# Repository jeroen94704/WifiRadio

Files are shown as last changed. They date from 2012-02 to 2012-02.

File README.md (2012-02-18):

WifiRadio
=========

Introduction
------------

This is the software part of my version of the ubiquitous wifi radio projects. There are many similar builds to be found online, 
and they all use a cheap router as an internet streaming radio, usually running MPD (http://mpd.wikia.com/wiki/Music_Player_Daemon_Wiki) 
to play the music. My build borrows heavily from the radio project by Jeff Keyzer, A.K.A. MightyOhm. He documented the process he 
went through in great detail on his blog, at http://mightyohm.com/blog/2008/10/building-a-wifi-radio-part-1-introduction/

In addition, I also owe a great deal to the SparkFun tutorial "Beginning embedded electronics", which can be found at 
http://www.sparkfun.com/tutorials/57

Contents
--------

The repository contains the following:

* C-code, to be compiled and programmed onto a suitable AVR microcontroller
* A perl script, which runs on the router
* Eagle schematics and board files of the electronics

Features
--------

The firmware+perl script system has the following features:

* Load a predefined playlist containing a set of internet streams
* Browse and play from an MP3 collection located on a network share
* Show currently playing information, including progress in the current track, title/artist info and playlist info

Usage
-----

The player is controlled using a 6-button keypad, with up/down/left/right/enter keys, and a mode switch key. The player starts in radio mode, 
playing the predefined set of internet streams. Pressing the mode switch key will start the MP3 browser mode, and shows the first few MP3 directories 
(in my case, artists). The browser is fully file based, so ID3 tags inside the MP3's are not interpreted. Use up/down to move through the list, press 
"right" to enter a directory, and show what's inside. Press "left" to go up one directory level. Press "enter" to play the currently selected item. If
this is a directory, everything inside that directory and its subdirectories will be played. Pressing the mode switch button again will reload and play
the predefined internet streams once more.

While playing, left/right let you move through the playlist, while up/down controls the volume (not shown on the display).
	
Technical details
-----------------
	
### C-Code

The code was built using the WinAVR suite of tools. You can use the included makefile to build your own binary, which includes targets to set the fuses and program the MPU.

### Perl script

This is a firm departure from Jeff's build, which uses bash scripting to do all the router-side processing. Since I need fairly elaborate two-way communication, involving
a lot of string parsing, using Perl with its built-in regex support was a logical move. The code is a bit dirty in the way it handles 2-way requests (e.g. When the AVR 
asks for a list of tracks). These requests involve receiving a message, processing it, and sending a result back to the AVR. The script forks at startup, so the receiving
and sending parts run in different processes.

When a results needs to be returned to the AVR, the receiver process writes a file containing the response. The sender process detects the existance if this file, reads it, 
sends the data over the serial line, and removes the file. 

More investigation is needed to determine whether the fork is actually necessary. An alternative would be to move to C, and use a proper multithreading approach, but I've 
cracked my skull against setting up an OpenWrt toolchain in the past, and have no immediate desire to attempt this again, also since the current implementation works just fine.

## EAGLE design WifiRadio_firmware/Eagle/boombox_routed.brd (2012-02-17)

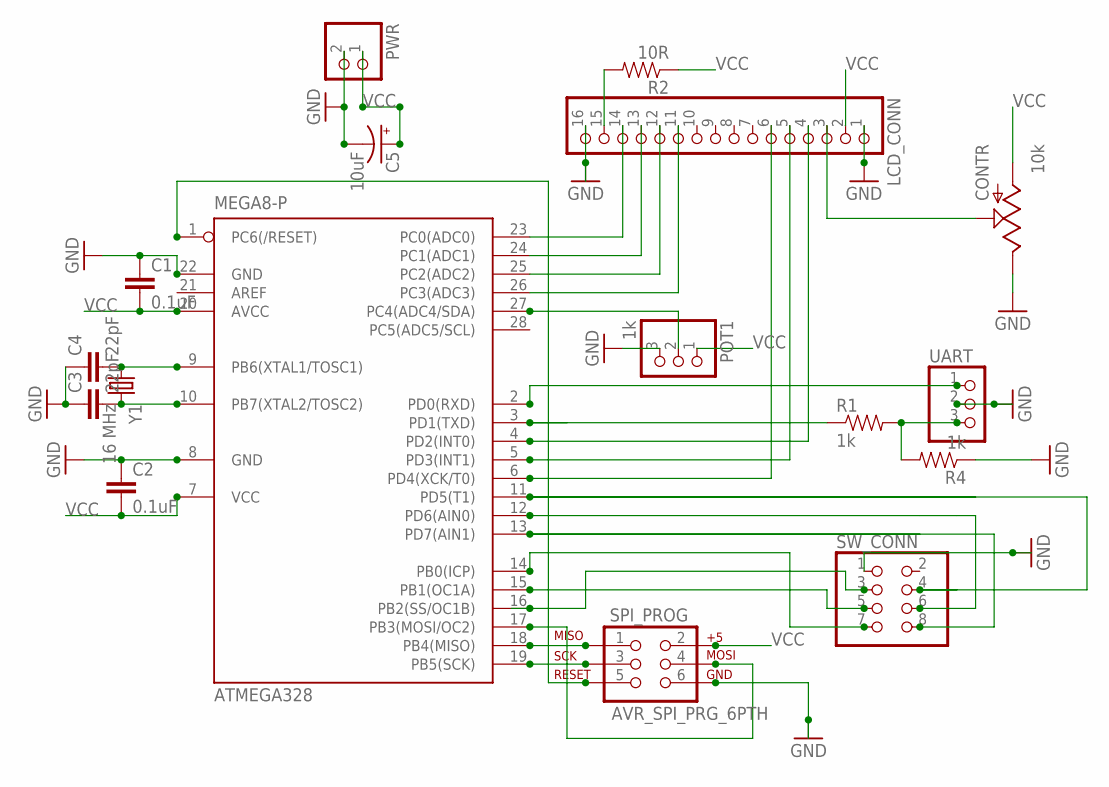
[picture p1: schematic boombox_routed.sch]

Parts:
ATMEGA328: MEGA8-P; DIL28-3
C1, C2: 0.1uF; C2.5-2
C3, C4: 22pF; C2.5-2
C5: 10uF; CPOL-RADIAL-10UF-25V
CONTR: 10k; 3362U
LCD_CONN: PINHD-1X16; 1X16
POT1: 1k; 1X03
PWR: PINHD-1X2; 1X02
R1, R4: 1k; AXIAL-0.4
R2: 10R; AXIAL-0.4
SPI_PROG: AVR_SPI_PRG_6PTH; 2X3
SW_CONN: PINHD-2X4; 2X04
UART: PINHD-1X3; 1X03
Y1: 16 MHz; HC49US

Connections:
GND: ATMEGA328.8 (GND), ATMEGA328.22 (GND), C1.1, C2.1, C3.1, C4.1, C5.2 (-), CONTR.P$1 (E), LCD_CONN.1, LCD_CONN.16, POT1.3, PWR.2, R4.P$1 (1), SPI_PROG.6, SW_CONN.1, UART.2
unnamed: ATMEGA328.10 (PB7(XTAL2/TOSC2)), C3.2, Y1.2
unnamed: ATMEGA328.9 (PB6(XTAL1/TOSC1)), C4.2, Y1.1
unnamed: CONTR.P$2 (S), LCD_CONN.3
unnamed: ATMEGA328.3 (PD1(TXD)), R1.P$1 (1)
unnamed: R1.P$2 (2), R4.P$2 (2), UART.3
unnamed: ATMEGA328.2 (PD0(RXD)), UART.1
unnamed: ATMEGA328.4 (PD2(INT0)), LCD_CONN.4
unnamed: ATMEGA328.5 (PD3(INT1)), LCD_CONN.5
unnamed: ATMEGA328.6 (PD4(XCK/T0)), LCD_CONN.6
unnamed: LCD_CONN.15, R2.P$2 (2)
unnamed: ATMEGA328.23 (PC0(ADC0)), LCD_CONN.14
unnamed: ATMEGA328.24 (PC1(ADC1)), LCD_CONN.13
unnamed: ATMEGA328.25 (PC2(ADC2)), LCD_CONN.12
unnamed: ATMEGA328.26 (PC3(ADC3)), LCD_CONN.11
unnamed: ATMEGA328.19 (PB5(SCK)), SPI_PROG.3
unnamed: ATMEGA328.18 (PB4(MISO)), SPI_PROG.1
unnamed: ATMEGA328.17 (PB3(MOSI/OC2)), SPI_PROG.4
unnamed: ATMEGA328.14 (PB0(ICP)), SW_CONN.7
unnamed: ATMEGA328.27 (PC4(ADC4/SDA)), POT1.2
unnamed: ATMEGA328.15 (PB1(OC1A)), SW_CONN.5
unnamed: ATMEGA328.12 (PD6(AIN0)), SW_CONN.6
unnamed: ATMEGA328.13 (PD7(AIN1)), SW_CONN.8
unnamed: ATMEGA328.11 (PD5(T1)), SW_CONN.4
unnamed: ATMEGA328.16 (PB2(SS/OC1B)), SW_CONN.3
unnamed: ATMEGA328.1 (PC6(/RESET)), SPI_PROG.5
VCC: ATMEGA328.7 (VCC), ATMEGA328.20 (AVCC), C1.2, C2.2, C5.1 (+), CONTR.P$3 (A), LCD_CONN.2, POT1.1, PWR.1, R2.P$1 (1), SPI_PROG.2

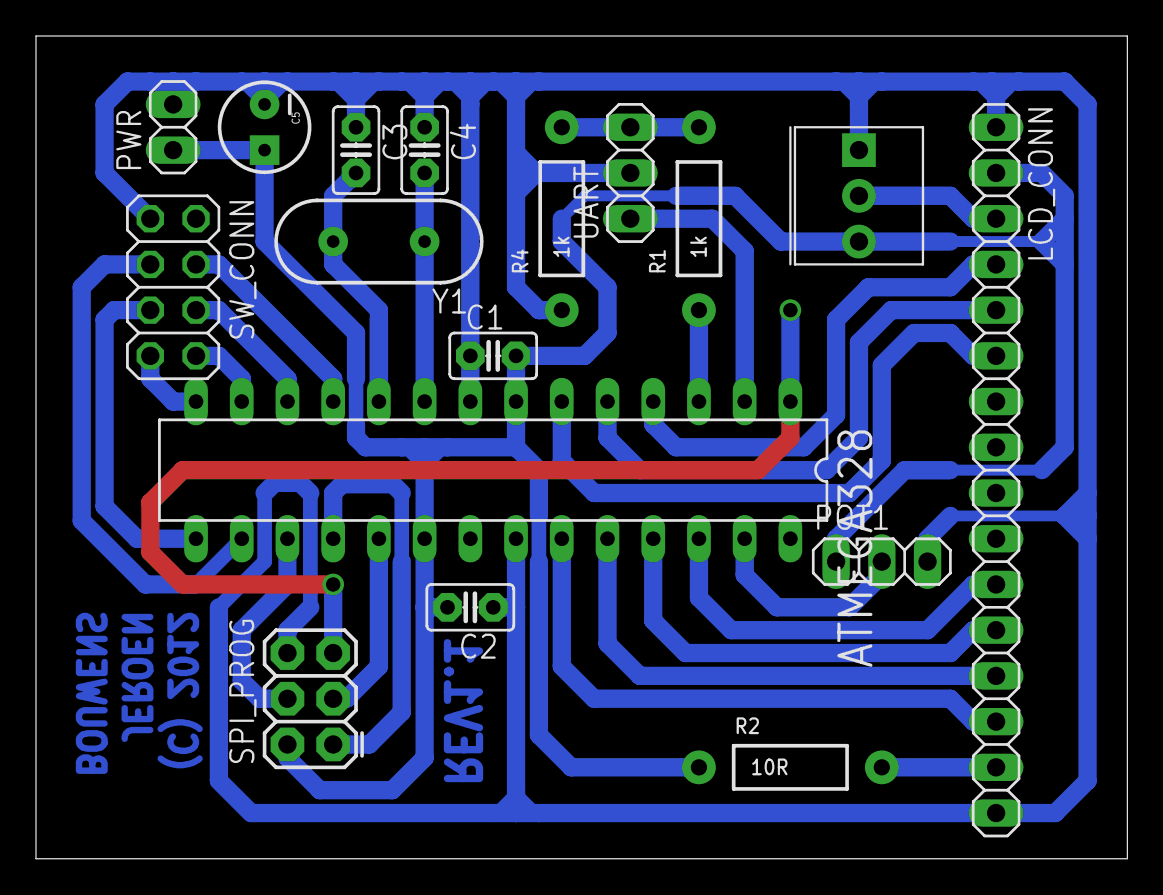
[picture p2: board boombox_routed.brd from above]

Board: 2 copper layers, 60.6 x 45.7 mm, 17 parts (0 on the bottom side), 27 nets.

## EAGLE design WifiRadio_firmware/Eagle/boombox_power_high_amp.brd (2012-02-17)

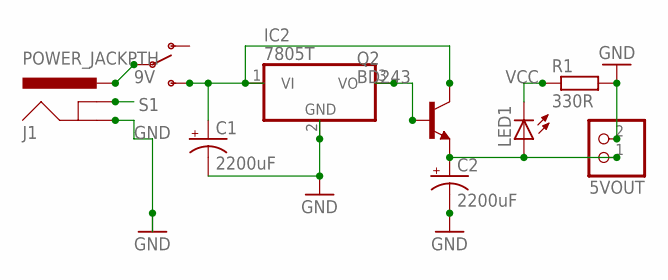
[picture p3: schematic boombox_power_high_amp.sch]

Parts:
5VOUT: PINHD-1X2/90; 1X02/90
C1, C2: 2200uF; CPOL-RADIAL-1000UF-25V
IC2: 7805T; TO220H
J1: POWER_JACKPTH; POWER_JACK_PTH
LED1: LED3MM
Q2: BD243; TO220
R1: 330R; 0309V
S1: SWITCH-SPSTPTH; SWITCH-SPDT

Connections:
9V: C1.1 (+), IC2.1 (VI), Q2.2 (C), S1.3 (S)
GND: 5VOUT.2, C1.2 (-), C2.2 (-), IC2.2 (GND), J1.GND, R1.2
unnamed: 5VOUT.1, C2.1 (+), LED1.A, Q2.3 (E)
unnamed: LED1.K (C), R1.1
unnamed: J1.PWR, S1.2
VCC: IC2.3 (VO), Q2.1 (B)

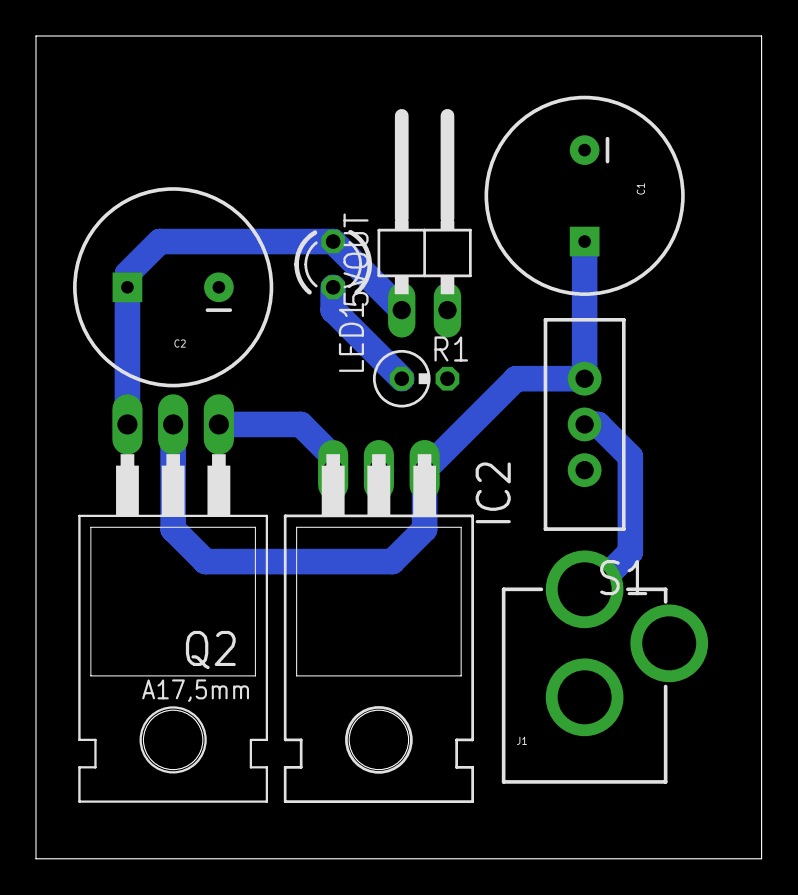
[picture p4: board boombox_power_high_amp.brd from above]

Board: 2 copper layers, 40.3 x 45.7 mm, 9 parts (0 on the bottom side), 6 nets.

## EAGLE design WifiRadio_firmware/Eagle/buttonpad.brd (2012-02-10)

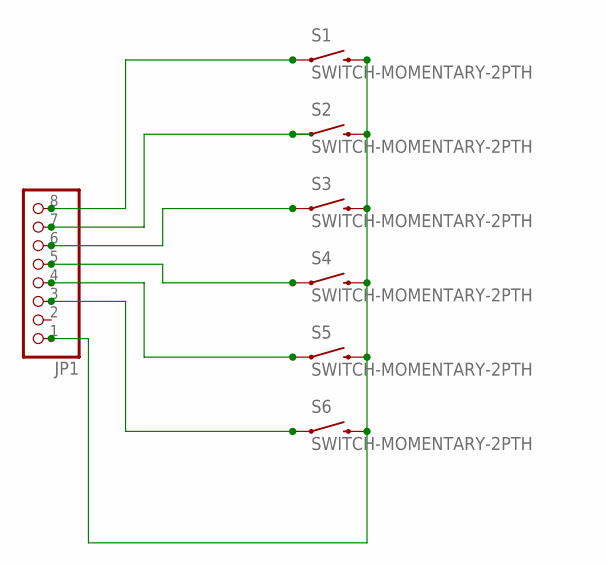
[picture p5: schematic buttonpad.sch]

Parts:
JP1: PINHD-1X8; 1X08
S1, S2, S3, S4, S5, S6: SWITCH-MOMENTARY-2PTH; TACTILE-PTH

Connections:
GND: JP1.1, S1.3 (2), S2.3 (2), S3.3 (2), S4.3 (2), S5.3 (2), S6.3 (2)
unnamed: JP1.8, S1.1
unnamed: JP1.6, S3.1
unnamed: JP1.3, S6.1
unnamed: JP1.7, S2.1
unnamed: JP1.5, S4.1
unnamed: JP1.4, S5.1

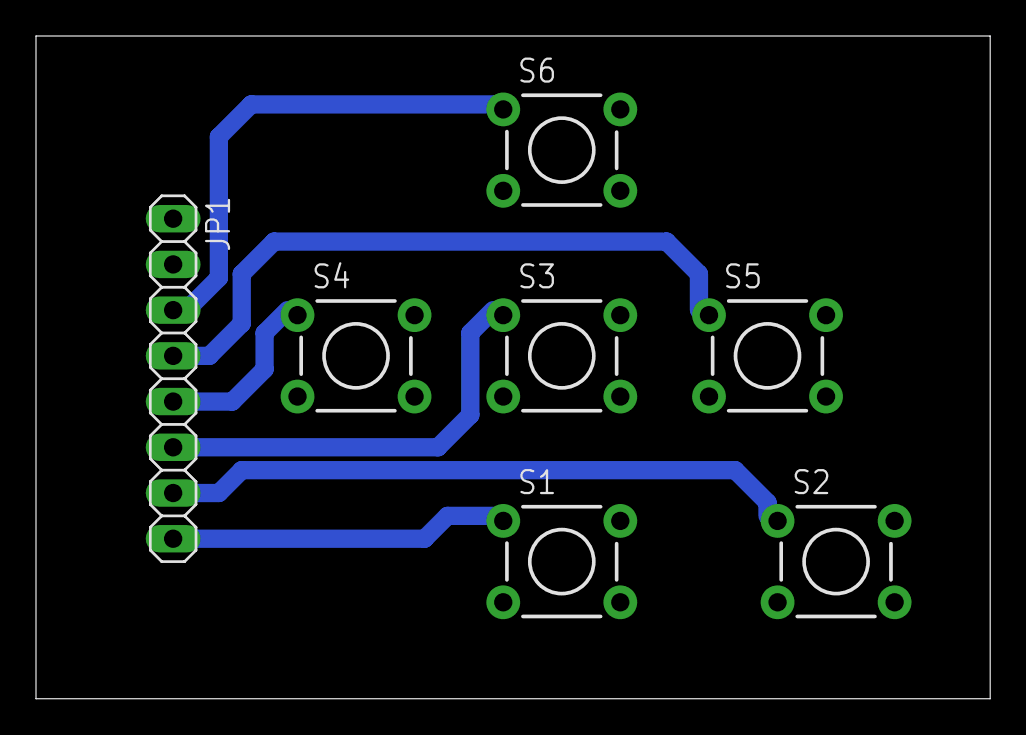
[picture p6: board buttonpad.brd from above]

Board: 2 copper layers, 53.0 x 36.8 mm, 7 parts (0 on the bottom side), 7 nets.

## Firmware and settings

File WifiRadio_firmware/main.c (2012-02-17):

/*
 * Firmware (c)2012 Jeroen Bouwens. Parts of the code were lifted from Jeff Keyzer's 
 * code, and from the SparkFun turorial on beginning embedded electronics. 
 * More information at:
 *
 * http://mightyohm.com/blog/
 *
 * and 
 *
 * http://www.sparkfun.com/tutorials/93
 *
 * Built and tested with an ATmega368 @ 16MHz and a Sparkfun 20x4 character LCD display
 *
 */

//=========== Includes ===========

#include <avr/io.h>
#include <avr/interrupt.h>
#include <util/delay.h>
#include <string.h>
#include <stdio.h>

#include "lcd.h"				// Peter Fleury's LCD Library

//=========== Defines ===========

#define	SER_BUFF_LEN	200		// longest character line to accept from serial port
#define STR_LEN			21		// Longest substring (artist, trackname) to accept. Width of the display + terminating 0
#define	BAUD			9600	// USART baud rate, must agree with router ttyS0 settings
#define	LCD_WIDTH		20		// visible width of LCD display
#define	PAGEDELAY		3000	// delay between LCD pages, in ms

#define BOOL unsigned char
#define TRUE 1
#define FALSE 0

#define UPBUTTON 0
#define DOWNBUTTON 1
#define LEFTBUTTON 2
#define RIGHTBUTTON 3
#define ENTERBUTTON 4
#define SWITCHBUTTON 5

#define UPBUTTONPIN PINB&4
#define DOWNBUTTONPIN PIND&128
#define LEFTBUTTONPIN PINB&2
#define RIGHTBUTTONPIN PIND&32
#define ENTERBUTTONPIN PIND&64
#define SWITCHBUTTONPIN PINB&1

#define PM_PLAYING 0
#define PM_BROWSING 2

//=========== Function prototypes ===========

int atoi ( const char * str );

void inituart(void);
void ioinit(void);
void uart_putchar(unsigned char data);
unsigned char uart_getchar(void);
void uart_flush(void);
void getline(char *serbuffer);
void putstring(char *buffer);
void init_timer1(void);

void lcd_print(char *s);
void processPlayingLine(char *RXserbuffer, char *artist, char *title, int *playlistLength, int *songNum, int *songTime, int *songElapsed);
void displayTime(int songElapsed, int playlistLength, int songNum);
void displayProgressBar(int songLength, int songElapsed);
void displayTrackInfo(char *trackName, char *artistName);
void displayDirEntries(void);
BOOL processButtonPress(int buttonIndex, int buttonPin);
BOOL processResponse(char *RXserbuffer);
void sendCommand(char* command);
void sendCommandParams(char* cmd, int param1, int param2);

char serRXbuffer[SER_BUFF_LEN];	// serial buffer
char serTXbuffer[20];	// serial buffer


//=========== Global Variables ===========

unsigned char gButtonPressSeen;	// Bits used to keep track of which button presses have been seen
unsigned char gPlayerMode;		// Keep track whether we are playing something or browsing the collection
int gCurrentListSelectedIndex;	// The selected item in the sublist of 4 currently shown on the display
int gCurrentListStartIndex;		// The index in the total list of the first item in the current sublist of 4
char gDirEntries[4][STR_LEN];	// Buffer holding track/dir names to display in browsing mode
int gNumDirEntries;				// How many dir entries did I receive? (should always be 1,2,3 or 4)
BOOL gWaitingForReply;			// Indicates whether a request was sent to which a reply is expected but not yet received
int gTimeOutCounter;			// Counter for the response timeout mechanism (in case the router fails to respond)

// Timer1 overflow interrupt service routine (ISR)
SIGNAL (TIMER1_OVF_vect) // SIGNAL call makes sure we don't interrupt the interrupt
{
	TCNT1 = 0x10000 - (F_CPU/1024/10);	// Reset the timer
	
	// Timeout mechanism, just in case the router fails to respond to a button press for 
	// which I expect a reply
	if(gWaitingForReply && gTimeOutCounter < 20)
	{
		gTimeOutCounter++;
	}
	else
	{
		// Timeout occurred
		gWaitingForReply = FALSE;
		gTimeOutCounter=0;
	}
	
	// Don't process button presses while I am are waiting for a reply
	if(!gWaitingForReply)
	{
		// When I am playing, handle button presses accordingly
		if(gPlayerMode == PM_PLAYING)
		{
			if(processButtonPress(UPBUTTON, UPBUTTONPIN) == TRUE)
			{
				sendCommand("cmd:volup\n");  
			}
			if(processButtonPress(DOWNBUTTON, DOWNBUTTONPIN) == TRUE)
			{
				sendCommand("cmd:voldown\n");
			}
			if(processButtonPress(LEFTBUTTON, LEFTBUTTONPIN) == TRUE)
			{
				sendCommand("cmd:prev\n");
			}
			if(processButtonPress(RIGHTBUTTON, RIGHTBUTTONPIN) == TRUE)
			{
				sendCommand("cmd:next\n");
			}
			if(processButtonPress(SWITCHBUTTON, SWITCHBUTTONPIN) == TRUE)
			{
				gPlayerMode = PM_BROWSING;

				// Retrieve the first list of items to show
				gCurrentListStartIndex = 0;
				gCurrentListSelectedIndex = 0;
				sendCommand("cmd:getfirsttracks\n");  
				gWaitingForReply = TRUE;
			}
		}
		// When I am browsing, handle button presses accordingly
		else if(gPlayerMode == PM_BROWSING)
		{
			if(processButtonPress(UPBUTTON, UPBUTTONPIN) == TRUE)
			{
				// Move up in the current sublist of 4 until I hit the top.
				gCurrentListSelectedIndex--;
				if(gCurrentListSelectedIndex == -1 && gCurrentListStartIndex > 0)
				{
					// Move up 4 places in the total list, if this is still possible
					gCurrentListStartIndex -= 4;
					if(gCurrentListStartIndex < 0)
					{
						gCurrentListStartIndex = 0;
					}
					
					// Switching to the "previous" page, so set the bottom entry as selected
					gCurrentListSelectedIndex = 3;
					
					// Retrieve the new list of items to show
					sendCommandParams("gettracks", gCurrentListStartIndex, gCurrentListSelectedIndex);		
					gWaitingForReply = TRUE;
				}
				else
				{
					displayDirEntries();
				}
			}
				
			if(processButtonPress(DOWNBUTTON, DOWNBUTTONPIN) == TRUE)
			{
				// Move down in the current sublist of 4 until I hit the bottom.
				gCurrentListSelectedIndex++;
				
				if(gCurrentListSelectedIndex == 4)
				{
					// Move down 4 places in the total list
					gCurrentListStartIndex += 4;
					
					// Switching to the "next" page, so set the top entry as selected
					gCurrentListSelectedIndex = 0;
					
					// Retrieve the new list of items to show
					sendCommandParams("gettracks", gCurrentListStartIndex, gCurrentListSelectedIndex);		
					gWaitingForReply = TRUE;
				}	
				else
				{
					// In case of a sublist shorter than 4 items, make sure I don't go past the last item
					if(gCurrentListSelectedIndex >= gNumDirEntries)
					{
						gCurrentListSelectedIndex = gNumDirEntries - 1;
					}

					displayDirEntries();
				}
			}
			
			if(processButtonPress(LEFTBUTTON, LEFTBUTTONPIN) == TRUE)
			{
				sendCommand("cmd:dirup\n");
				gCurrentListStartIndex = 0;
				gCurrentListSelectedIndex = 0;
				gWaitingForReply = TRUE;
			}
			
			if(processButtonPress(RIGHTBUTTON, RIGHTBUTTONPIN) == TRUE)
			{
				sendCommandParams("dirdown", gCurrentListStartIndex, gCurrentListSelectedIndex);		
				gCurrentListStartIndex = 0;
				gCurrentListSelectedIndex = 0;
				gWaitingForReply = TRUE;
			}
			
			if(processButtonPress(ENTERBUTTON, ENTERBUTTONPIN) == TRUE)
			{
				gPlayerMode = PM_PLAYING;
				sendCommandParams("play", gCurrentListStartIndex, gCurrentListSelectedIndex);		
			}

			if(processButtonPress(SWITCHBUTTON, SWITCHBUTTONPIN) == TRUE)
			{
				gPlayerMode = PM_PLAYING;
				sendCommand("cmd:loadstreams\n");
			}
		}
	}
}

// Send a command with 2 parameters through the serial port 
void sendCommandParams(char* cmd, int param1, int param2)
{
	char stringBuffer[40];
	sprintf(stringBuffer, "cmd:%s %d %d\n", cmd, param1, param2);
	sendCommand(stringBuffer);		
}

// Handle a button press. This returns TRUE when a new button press on the selected pin is detected 
// Once a button press is detected, the function returns FALSE, until the button is released and 
// pressed again
BOOL processButtonPress(int buttonIndex, int buttonPin)
{
	BOOL result = FALSE;
	
	if(!(gButtonPressSeen & (1 << buttonIndex)))
	{
		if(!(buttonPin))
		{
			gButtonPressSeen |=  (1 << buttonIndex);
			result=TRUE;
		}
	}
	else
	{
		if((buttonPin))
		{
			gButtonPressSeen &=  !(1 << buttonIndex);
		}
		
	}
	
	return result;
}

// Send a string to the router through the serial port
void sendCommand(char* command)
{
	sprintf(serTXbuffer, command);	// Place command in send buffer
	putstring(serTXbuffer);	// transmit over serial link		
}

// Main function. Apart from some initialization, this function contains
// and endless loop which handles messages received from the router over 
// the serial line
int main(void)
{
	char artist[STR_LEN];	// Artist name
	char title[STR_LEN];	// Title of current song
	int playlistLength;		// Length of the playlist
	int songNum;			// song number in the current playlist
	int songTime;			// Total length of the song in seconds
	int songElapsed;		// Elapsed time within the song in seconds
	
    ioinit();		// Setup IO pins and defaults
    inituart();		// initialize AVR serial port (USART0)

	// Blink once to indicate succesful startup
	PORTC = 0b0100000;
	_delay_ms(100);
	PORTC = 0x00;   // All LED's are off

    // initialize LCD display
    lcd_init(LCD_DISP_ON);

    // Display splash screen
    lcd_clrscr();	
    lcd_puts("    MPD Boombox\n   Jeroen Bouwens\n Sponsored by Sioux\n  Embedded Systems");
    _delay_ms(2000);
	
	// Initialize variables and the timer
	gButtonPressSeen = 0;
	gPlayerMode = PM_PLAYING;
	init_timer1();
	sei();		// enable interrupts
    
    // Main program loop
    for(;;) // Loop forever
	{	
		// Grab a line of data from the serial port
		// Note: program execution will stall until serial data is received!
		getline(serRXbuffer);		

		// Blink once when a message was received
		PORTC |= 0b0100000;
		_delay_ms(100);
		PORTC &= 0b1011111;
			
		// If I am playing, show track info
		if(gPlayerMode == PM_PLAYING)
		{
			processPlayingLine(serRXbuffer, artist, title, &playlistLength, &songNum, &songTime, &songElapsed);
				
			lcd_clrscr();	// clear screen

			displayTime(songElapsed, playlistLength, songNum);
			displayProgressBar(songTime, songElapsed);
			displayTrackInfo(title, artist);
		}
		// If I am browsing 
		else
		{
			if(processResponse(serRXbuffer) == TRUE)
			{
				displayDirEntries();
			}
		}
    }
	 
    return 0;   // Never reached
}

void inituart(void)	// Initialize USART0 to desired baud rate
{
	// Set baud rate generator based on F_CPU
	UBRR0H = (unsigned char)(F_CPU/(16UL*BAUD)-1)>>8;
	UBRR0L = (unsigned char)(F_CPU/(16UL*BAUD)-1);
	
	// Enable USART0 transmitter and receiver
	UCSR0B = (1<<RXEN0) | (1<<TXEN0);

}

unsigned char uart_getchar(void)
{
	while(!(UCSR0A & (1 << RXC0)))	// wait until character is received
		;	// do nothing
	
	return UDR0;
}

void uart_putchar(unsigned char data)	// send a character over the serial port
{

	while(!(UCSR0A & (1 << UDRE0))) // wait until UART is ready for tx
		;       // do nothing
	UDR0 = data;    // send char

}

void uart_flush(void)	// flush RX buffer
{
	unsigned char dummy;
	
	while(UCSR0A & (1<<RXC0))	// while there is a character in the RX queue
		dummy = UDR0;			// flush the queue by reading it
}

void getline(char *buffer)	// get a single line from the UART rcvr
{
	int bufpos = 0;
	
	uart_flush();	// clear RX buffer of stale chars if present
	
	// read a line from UART, stop if buffer is full or we reach newline
	while ((bufpos < (SER_BUFF_LEN - 1)) && (buffer[bufpos] = uart_getchar()) != '\n') {

		if (buffer[bufpos] == '\r')
			bufpos--;	// strip carriage returns in case data contains both CR&LF
			
		bufpos++;
	}
	
	buffer[bufpos] = '\0';	// turn buffer into a string
}

void ioinit (void)
{
    //1 = output, 0 = input
    DDRC  |= 0b0100000; // PC5 is output
	
	DDRB  &= 0b11111000; // PB0, 1, 2 are input
	PORTB |= 0b00000111; // Enable internal pull-up resistors	

	DDRD  &= 0b00011111; // PB5, 6, 7 are input
	PORTD |= 0b11100000; // Enable internal pull-up resistors
}

void putstring(char *buffer)	// send a string to the UART
{
	int bufpos = 0;
	
	cli();	// disable interrupts so we don't mangle the data
	
	// start sending characters over the serial port until we reach the end of the string
	while ((bufpos < (SER_BUFF_LEN - 1)) && (buffer[bufpos] != '\0')) 
	{
		uart_putchar(buffer[bufpos]);
			
		bufpos++;
	}
	
	sei();	// enable interrupts again
	
}

void init_timer1(void) 
{
	// initialize TIMER1 to trigger an overflow interrupt every 0.5sec
	TCCR1A = 0;
	TCCR1B |= (1 << CS12) | (1 << CS10);

	
	TCNT1 = 0x10000 - (F_CPU/1024/4);
	
	TIFR1=0;
	TIMSK1 |= (1 << TOIE1);
}

// Process a message in the response format
BOOL processResponse(char *RXserbuffer)
{
	// The following code assumes the message has the following format:
	//		resp: param1,param2,param3,param4
	// It wil store the params in the gDirEntries array. Less than 4 params
	// will also work
	// NOTE: All params, including the last one, must be followed by a comma

	// Check if this is a response message
	char *responsePtr = strstr(RXserbuffer, "resp: ");
	if(responsePtr)
	{
		gNumDirEntries = 0;
		char *respStart = responsePtr + sizeof("resp: ") - 1; // Skip the indentifier part
		char *commaPtr = strstr(respStart, ","); 			   // Find the comma separating param1 and param2
		
		// Assume there are 4 parameters. If less than 4 are found, fill in blanks
		for(int i=0; i<4; i++)
		{
			if(commaPtr)
			{
				int strLen = commaPtr - respStart; 
				strncpy(gDirEntries[i], respStart , strLen);
				gDirEntries[i][strLen] = '\0';		// Make the string zero-terminated
				respStart = commaPtr+1;
				commaPtr = strstr(respStart, ",");
				gNumDirEntries++; 					// Some administration
			}
			else
			{
				gDirEntries[i][0] = '\0';	
			}
		}		
		gWaitingForReply = FALSE;
		return TRUE;
	}
	
	return FALSE;
}

// Process a message in the track information format
void processPlayingLine(char *RXserbuffer, char *artist, char *title, 
						int *playlistLength, int *songNum, int *songTime, int *songElapsed)
{
	// The following code assumes the message has one of the following two formats:
	//
	// 	Artis: <artist> Title: <title> playlistlength: <playlistlength> song: <song> time: <time>
	//
	//  Title: <title> Name: <name> playlistlength: <playlistlength> song: <song> time: <time>
	//
	// Time is in the format <elapsedSeconds>:<totalDurationSeconds>
	// The order of the fields DOES MATTER! 

	char *artistPtr 	= strstr(RXserbuffer, "Artist: ");
	char *titlePtr 		= strstr(RXserbuffer, "Title: ");
	char *namePtr		= strstr(RXserbuffer, "Name: ");
	char *plLengthPtr	= strstr(RXserbuffer, "playlistlength: ");
	char *songPtr 		= strstr(RXserbuffer, "song: ");
	char *timePtr 		= strstr(RXserbuffer, "time: ");

	int stringLength = 0;	

	if(artistPtr && titlePtr)
	{
		char *artistStart = artistPtr + sizeof("Artist: ") - 1;
		stringLength = titlePtr - (artistPtr + sizeof("Artist: ") - 1);
		stringLength = stringLength > 20 ? 20 : stringLength;
		strncpy(artist, artistStart , stringLength);
	}
	artist[stringLength] = '\0';
	
	stringLength = 0;
	if(titlePtr && namePtr) // If we're playing a stream the "artist" field will not be present and there will be a "name" field between title and playlistlength
	{
		char *titleStart = titlePtr + sizeof("Title: ") - 1;			// Skip the field name
		stringLength = namePtr - (titlePtr + sizeof("Title: ") - 1);	// Determine the length of the field value
		stringLength = stringLength > 20 ? 20 : stringLength; 			// Truncate to the maximum width of the display
		strncpy(title, titleStart, stringLength);						// Copy the field value to the appropriate buffer
	}
	else if(titlePtr && plLengthPtr) // There's no "name" field, so we're playing an MP3 and there will be a playlistlength field after the title
	{
		char *titleStart = titlePtr + sizeof("Title: ") - 1;
		stringLength = plLengthPtr - (titlePtr + sizeof("Title: ") - 1);
		stringLength = stringLength > 20 ? 20 : stringLength;
		strncpy(title, titleStart, stringLength);
		
	}
	title[stringLength] = '\0';
	
	if(namePtr && plLengthPtr)
	{
		char *nameStart = namePtr + sizeof("Name: ") - 1;
		stringLength = plLengthPtr - (namePtr + sizeof("Name: ") - 1);
		stringLength = stringLength > 20 ? 20 : stringLength;
		strncpy(artist, nameStart , stringLength);
		artist[stringLength] = '\0';
	}
	
	if(plLengthPtr && songPtr)
	{
		char *pllStart = plLengthPtr + sizeof("playlistlength: ") - 1;
		stringLength = songPtr - (plLengthPtr + sizeof("playlistlength: ") - 1);
		pllStart[stringLength] = '\0';
		*playlistLength = atoi(pllStart);
	}
	
	if(songPtr && timePtr)
	{
		char *songStart = songPtr + sizeof("song: ") - 1;
		stringLength = timePtr - (songPtr + sizeof("song: ") - 1);
		songStart[stringLength] = '\0';
		*songNum = atoi(songStart) + 1;
	}
	
	if(timePtr)
	{
		char *timeStart = timePtr + sizeof("time: ") - 1;
		char *songTotalTime = strstr(timeStart, ":") + 1;
		*(songTotalTime-1) = '\0'; // Insert a terminating \0 to separate the elapsed time from the total time
		*songElapsed = atoi(timeStart);
		*songTime = atoi(songTotalTime);
	}	
}

// Display the track name and artist, or the stream name and track name
void displayTrackInfo(char *trackName, char *artistName)
{

	lcd_gotoxy(10-strlen(artistName)/2,1);
	lcd_puts(artistName);

	lcd_gotoxy(10-strlen(trackName)/2,2);
	lcd_puts(trackName);
} 

// Display the progress bar that indicates the percentage of a track that has 
// elapsed. Note that this will have no function when playing a stream, since
// this function needs to know how long a track lasts, which is unknown for a 
// stream
void displayProgressBar(int songLength, int songElapsed)
{
	if(songLength > 0)
	{
		// Elapsed part
		for(int i=0; i<((songElapsed*100)/songLength)/5; i++)
		{
			lcd_gotoxy(i, 3);
			lcd_putc('#');
		}
		
		// Still remaining part
		for(int i=((songElapsed*100)/songLength)/5; i<20; i++)
		{
			lcd_gotoxy(i, 3);
			lcd_putc('-');
		}
	}
	else
	{
		// Playing a stream, fill with '-'s
		for(int i=0; i<20; i++)
		{
			lcd_gotoxy(i, 3);
			lcd_putc(' ');
		}		
	}
}

// Display the track elapsed time, and the playlist info (position in playlist + playlist length)
void displayTime(int songElapsed, int playlistLength, int songNum)
{
	char stringBuffer[20];
 
	sprintf(stringBuffer, "%d:%02d", songElapsed / 60, songElapsed % 60);
	lcd_gotoxy(0, 0);
	lcd_puts(stringBuffer);

	sprintf(stringBuffer, "(%d of %d)", songNum, playlistLength);
	lcd_gotoxy(20-strlen(stringBuffer), 0);
	lcd_puts(stringBuffer);
}

// Display the (at most) 4 directory entries received from the router, and indicate which
// is the currently selected one.
void displayDirEntries()
{
	lcd_clrscr();
			
	for(int y=0; y<4; y++)
	{
		lcd_gotoxy(1, y);
		lcd_puts(gDirEntries[y]);
		
		if(y == gCurrentListSelectedIndex)
		{
			lcd_gotoxy(0, y);
			lcd_puts(">");
		}
	}
}

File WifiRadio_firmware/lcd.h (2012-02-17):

#ifndef LCD_H
#define LCD_H
/*************************************************************************
 Title	:   C include file for the HD44780U LCD library (lcd.c)
 Author:    Peter Fleury <pfleury@gmx.ch>  http://jump.to/fleury
 File:	    $Id: lcd.h,v 1.13.2.2 2006/01/30 19:51:33 peter Exp $
 Software:  AVR-GCC 3.3
 Hardware:  any AVR device, memory mapped mode only for AT90S4414/8515/Mega
***************************************************************************/

/**
 @defgroup pfleury_lcd LCD library
 @code #include <lcd.h> @endcode
 
 @brief Basic routines for interfacing a HD44780U-based text LCD display

 Originally based on Volker Oth's LCD library,
 changed lcd_init(), added additional constants for lcd_command(), 
 added 4-bit I/O mode, improved and optimized code.
       
 Library can be operated in memory mapped mode (LCD_IO_MODE=0) or in 
 4-bit IO port mode (LCD_IO_MODE=1). 8-bit IO port mode not supported.

 Memory mapped mode compatible with Kanda STK200, but supports also 
 generation of R/W signal through A8 address line.
       
 @author Peter Fleury pfleury@gmx.ch http://jump.to/fleury
 
 @see The chapter <a href="http://homepage.sunrise.ch/mysunrise/peterfleury/avr-lcd44780.html" target="_blank">Interfacing a HD44780 Based LCD to an AVR</a>
      on my home page.

*/

/*@{*/

#if (__GNUC__ * 100 + __GNUC_MINOR__) < 303
#error "This library requires AVR-GCC 3.3 or later, update to newer AVR-GCC compiler !"
#endif

#include <inttypes.h>
#include <avr/pgmspace.h>

/** 
 *  @name  Definitions for MCU Clock Frequency
 *  Adapt the MCU clock frequency in Hz to your target. 
 */
#define XTAL F_CPU              /**< clock frequency in Hz, used to calculate delay timer */


/**
 * @name  Definition for LCD controller type
 * Use 0 for HD44780 controller, change to 1 for displays with KS0073 controller.
 */
#define LCD_CONTROLLER_KS0073 0  /**< Use 0 for HD44780 controller, 1 for KS0073 controller */

/** 
 *  @name  Definitions for Display Size 
 *  Change these definitions to adapt setting to your display
 */
#define LCD_LINES           4     /**< number of visible lines of the display */
#define LCD_DISP_LENGTH    20    /**< visibles characters per line of the display */
#define LCD_LINE_LENGTH	   40   /**< internal line length of the display    */
#define LCD_START_LINE1  0x00     /**< DDRAM address of first char of line 1 */
#define LCD_START_LINE2  0x40     /**< DDRAM address of first char of line 2 */
#define LCD_START_LINE3  0x14     /**< DDRAM address of first char of line 3 */
#define LCD_START_LINE4  0x54     /**< DDRAM address of first char of line 4 */
#define LCD_WRAP_LINES      0     /**< 0: no wrap, 1: wrap at end of visibile line */


#define LCD_IO_MODE      1         /**< 0: memory mapped mode, 1: IO port mode */
#if LCD_IO_MODE
/**
 *  @name Definitions for 4-bit IO mode
 *  Change LCD_PORT if you want to use a different port for the LCD pins.
 *
 *  The four LCD data lines and the three control lines RS, RW, E can be on the 
 *  same port or on different ports. 
 *  Change LCD_RS_PORT, LCD_RW_PORT, LCD_E_PORT if you want the control lines on
 *  different ports. 
 *
 *  Normally the four data lines should be mapped to bit 0..3 on one port, but it
 *  is possible to connect these data lines in different order or even on different
 *  ports by adapting the LCD_DATAx_PORT and LCD_DATAx_PIN definitions.
 *  
 */
#define LCD_PORT         PORTC        /**< port for the LCD lines   */
#define LCD_DATA0_PORT   LCD_PORT     /**< port for 4bit data bit 0 */
#define LCD_DATA1_PORT   LCD_PORT     /**< port for 4bit data bit 1 */
#define LCD_DATA2_PORT   LCD_PORT     /**< port for 4bit data bit 2 */
#define LCD_DATA3_PORT   LCD_PORT     /**< port for 4bit data bit 3 */
#define LCD_DATA0_PIN    3            /**< pin for 4bit data bit 0  */
#define LCD_DATA1_PIN    2            /**< pin for 4bit data bit 1  */
#define LCD_DATA2_PIN    1            /**< pin for 4bit data bit 2  */
#define LCD_DATA3_PIN    0            /**< pin for 4bit data bit 3  */
#define LCD_RS_PORT      PORTD     /**< port for RS line         */
#define LCD_RS_PIN       2            /**< pin  for RS line         */
#define LCD_RW_PORT      PORTD     /**< port for RW line         */
#define LCD_RW_PIN       3            /**< pin  for RW line         */
#define LCD_E_PORT       PORTD     /**< port for Enable line     */
#define LCD_E_PIN        4            /**< pin  for Enable line     */

#elif defined(__AVR_AT90S4414__) || defined(__AVR_AT90S8515__) || defined(__AVR_ATmega64__) || \
      defined(__AVR_ATmega8515__)|| defined(__AVR_ATmega103__) || defined(__AVR_ATmega128__) || \
      defined(__AVR_ATmega161__) || defined(__AVR_ATmega162__)
/*
 *  memory mapped mode is only supported when the device has an external data memory interface
 */
#define LCD_IO_DATA      0xC000    /* A15=E=1, A14=RS=1                 */
#define LCD_IO_FUNCTION  0x8000    /* A15=E=1, A14=RS=0                 */
#define LCD_IO_READ      0x0100    /* A8 =R/W=1 (R/W: 1=Read, 0=Write   */
#else
#error "external data memory interface not available for this device, use 4-bit IO port mode"

#endif


/**
 *  @name Definitions for LCD command instructions
 *  The constants define the various LCD controller instructions which can be passed to the 
 *  function lcd_command(), see HD44780 data sheet for a complete description.
 */

/* instruction register bit positions, see HD44780U data sheet */
#define LCD_CLR               0      /* DB0: clear display                  */
#define LCD_HOME              1      /* DB1: return to home position        */
#define LCD_ENTRY_MODE        2      /* DB2: set entry mode                 */
#define LCD_ENTRY_INC         1      /*   DB1: 1=increment, 0=decrement     */
#define LCD_ENTRY_SHIFT       0      /*   DB2: 1=display shift on           */
#define LCD_ON                3      /* DB3: turn lcd/cursor on             */
#define LCD_ON_DISPLAY        2      /*   DB2: turn display on              */
#define LCD_ON_CURSOR         1      /*   DB1: turn cursor on               */
#define LCD_ON_BLINK          0      /*     DB0: blinking cursor ?          */
#define LCD_MOVE              4      /* DB4: move cursor/display            */
#define LCD_MOVE_DISP         3      /*   DB3: move display (0-> cursor) ?  */
#define LCD_MOVE_RIGHT        2      /*   DB2: move right (0-> left) ?      */
#define LCD_FUNCTION          5      /* DB5: function set                   */
#define LCD_FUNCTION_8BIT     4      /*   DB4: set 8BIT mode (0->4BIT mode) */
#define LCD_FUNCTION_2LINES   3      /*   DB3: two lines (0->one line)      */
#define LCD_FUNCTION_10DOTS   2      /*   DB2: 5x10 font (0->5x7 font)      */
#define LCD_CGRAM             6      /* DB6: set CG RAM address             */
#define LCD_DDRAM             7      /* DB7: set DD RAM address             */
#define LCD_BUSY              7      /* DB7: LCD is busy                    */
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

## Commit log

2011-12-22 Added second button (now used to reload the standard playlist).
2011-12-29 Started implementation of track browser
2012-01-29 Added eagle design files
    [boombox_power_high_amp.brd, boombox_power_high_amp.sch, boombox_routed.brd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]
2012-01-30 Fixed DRC warnings
    [boombox_routed.brd]
2012-01-31 Finished manual routing
    [boombox_routed.brd]
2012-01-31 Modified everything to avoid 90 degree angles
    [boombox_routed.brd]
2012-01-31 Fixed small error
    [boombox_routed.brd]
2012-01-31 More angle changes
    [boombox_routed.brd]
2012-01-31 some small changes
    [boombox_routed.sch]
2012-02-01 Added back the 10 uF stabilizing cap
    [boombox_routed.brd]
2012-02-10 Added schematics for a buttonpad and display gender changer.
    [buttonpad.brd, buttonpad.sch, display gender changer.brd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]
2012-02-17 Modified boards, changed pin asignment in lcd driver
    [boombox_power_high_amp.brd, boombox_power_high_amp.sch, boombox_routed.brd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]
2012-02-17 Removed unused files
    [display gender changer.brd, display gender changer.sch]

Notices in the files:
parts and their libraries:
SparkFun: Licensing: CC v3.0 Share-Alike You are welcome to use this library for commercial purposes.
